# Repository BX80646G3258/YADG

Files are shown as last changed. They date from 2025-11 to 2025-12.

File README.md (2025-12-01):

# Yet Another Dogshit Gamepad
YADG is an open source gamepad built on the Arduino platform.
## Features
- 1000hz polling rate
- Polar joystick input
- Curve map
- Configurable deadzones
- Button remapping
- Button debounce settings
- idk what people care about lol
## Images
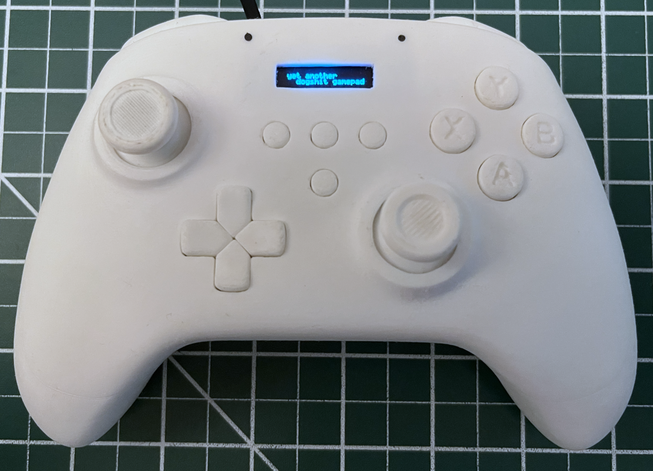
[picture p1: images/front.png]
front of YADG gamepad

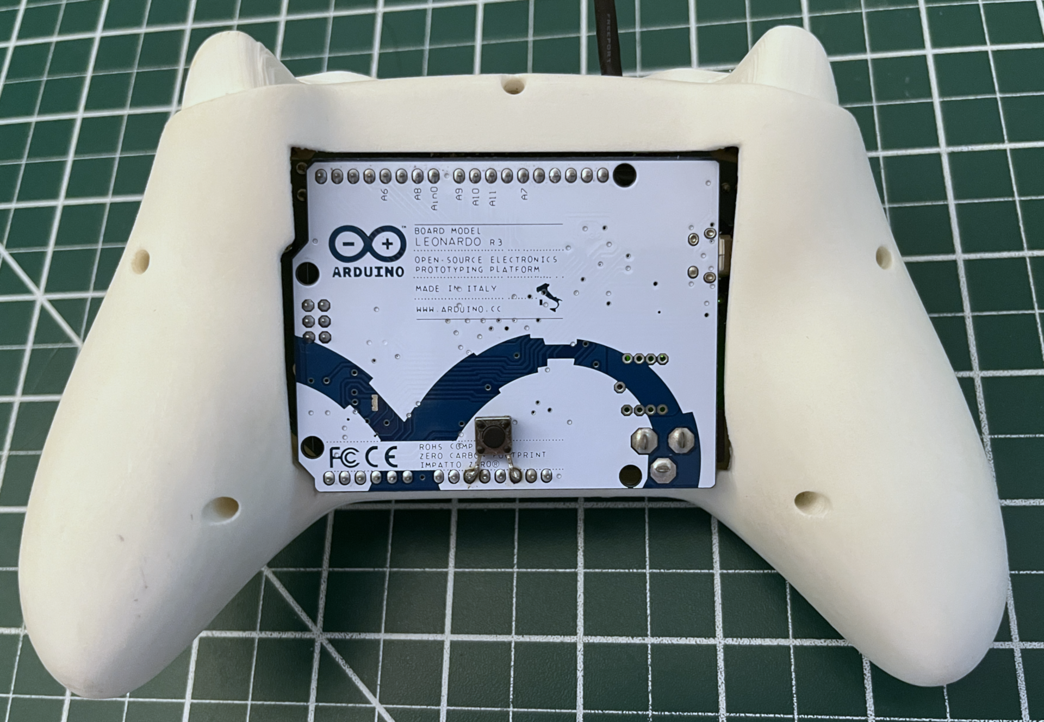
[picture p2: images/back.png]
back of YADG gamepad


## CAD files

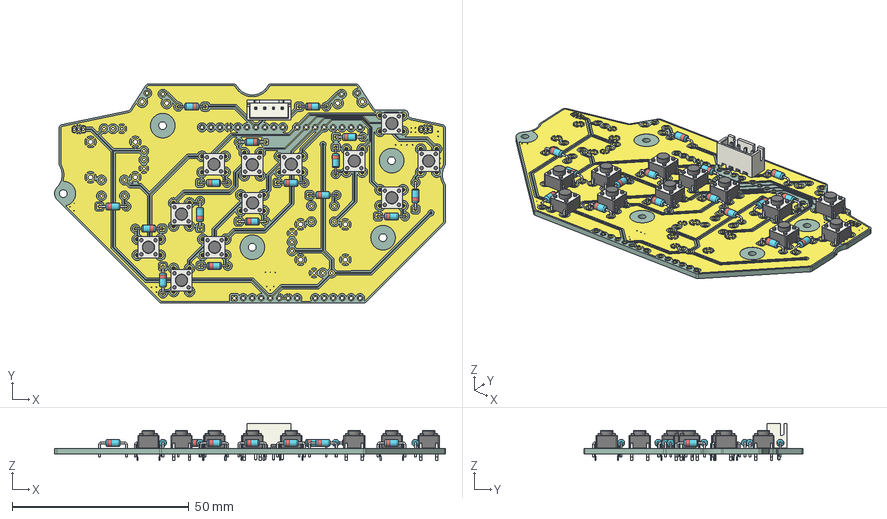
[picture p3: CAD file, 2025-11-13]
pcb/controller.step
110.5 x 61.9 x 10.5 mm
SW_PUSH_6mm_H5mm x 12
D_DO-35_SOD27_P7.62mm_Horizontal x 16
JST_XH_B4B-XH-A_1x04_P2.50mm_Vertical
controller_copper
controller_PCB

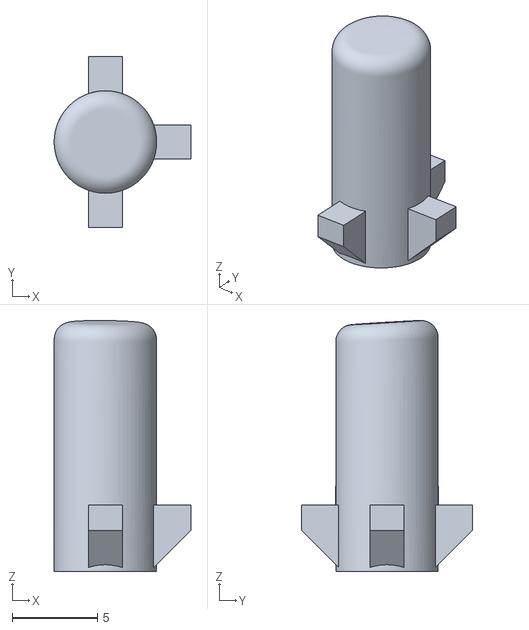
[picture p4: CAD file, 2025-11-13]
stl/start button.stl
8.00 x 10.0 x 14.7

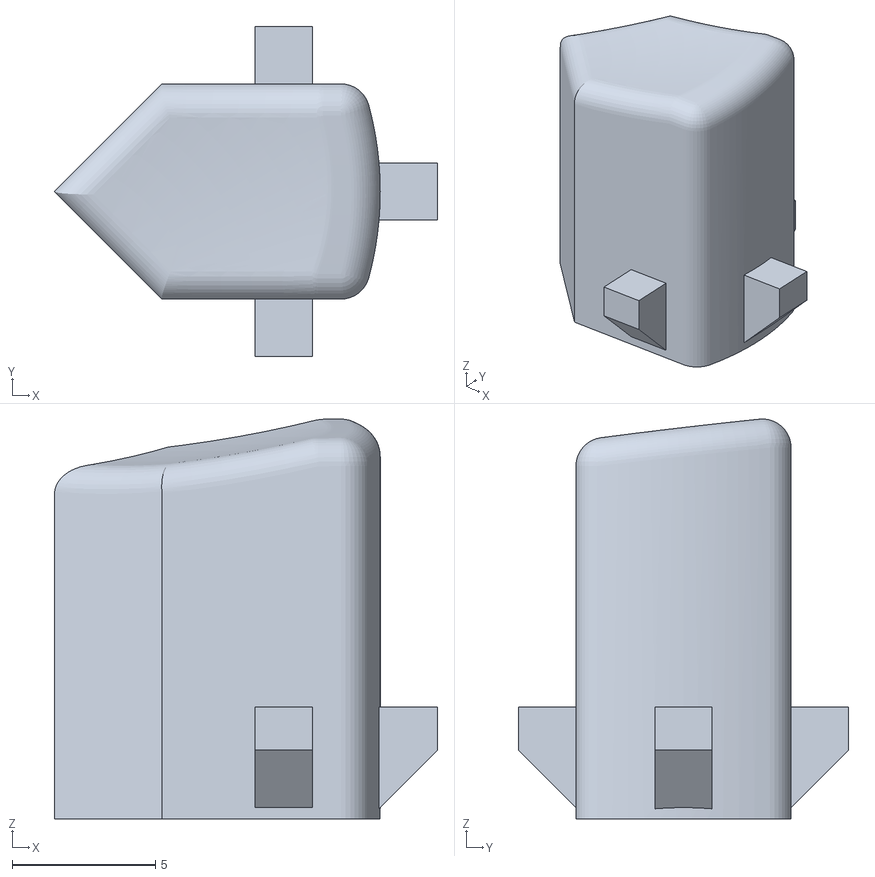
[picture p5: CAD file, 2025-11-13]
stl/dpad right button.stl
13.4 x 11.5 x 13.9

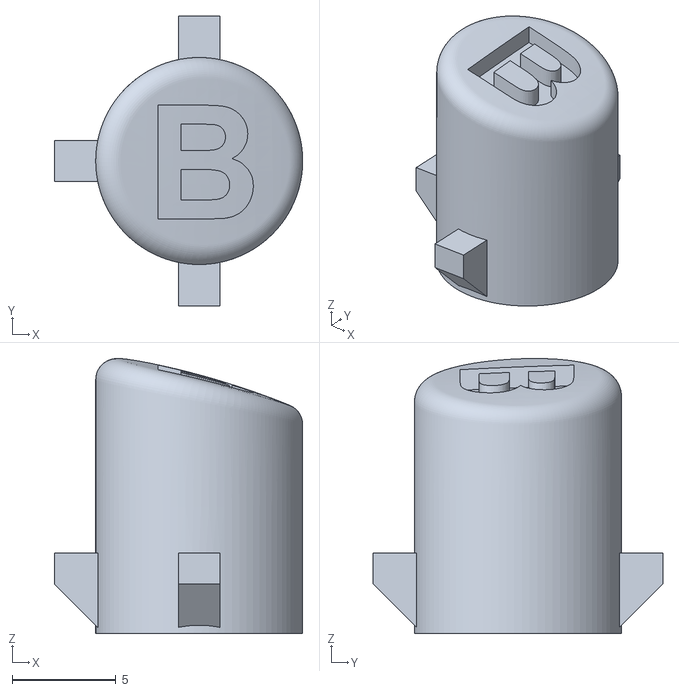
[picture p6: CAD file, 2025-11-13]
stl/button B.stl
12.0 x 14.0 x 13.3

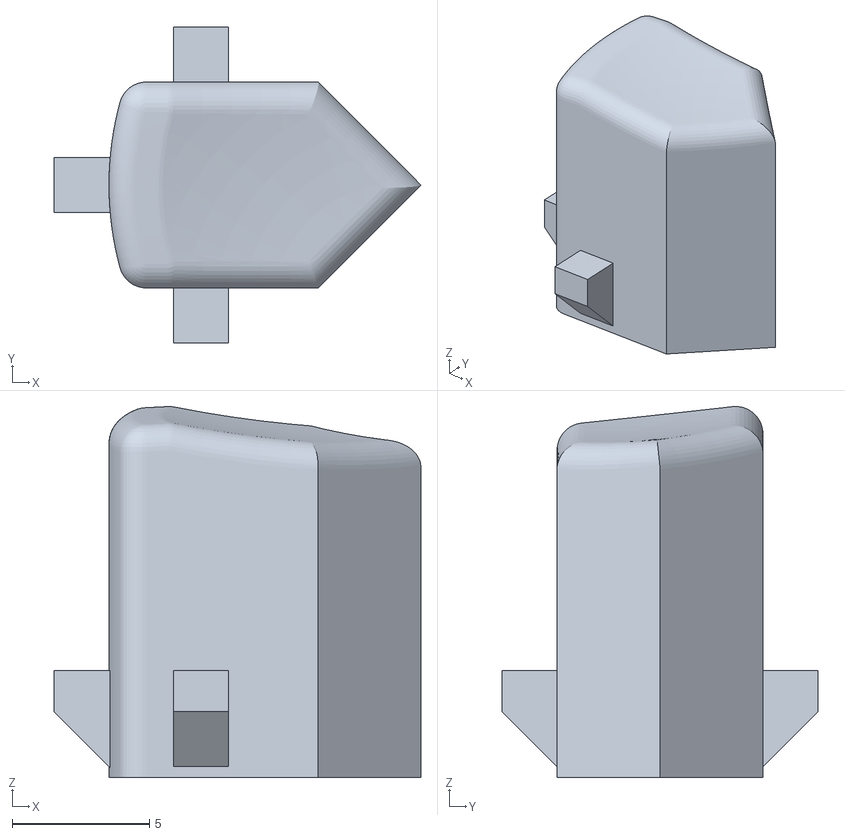
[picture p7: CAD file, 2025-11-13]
stl/dpad left button.stl
13.4 x 11.5 x 13.5

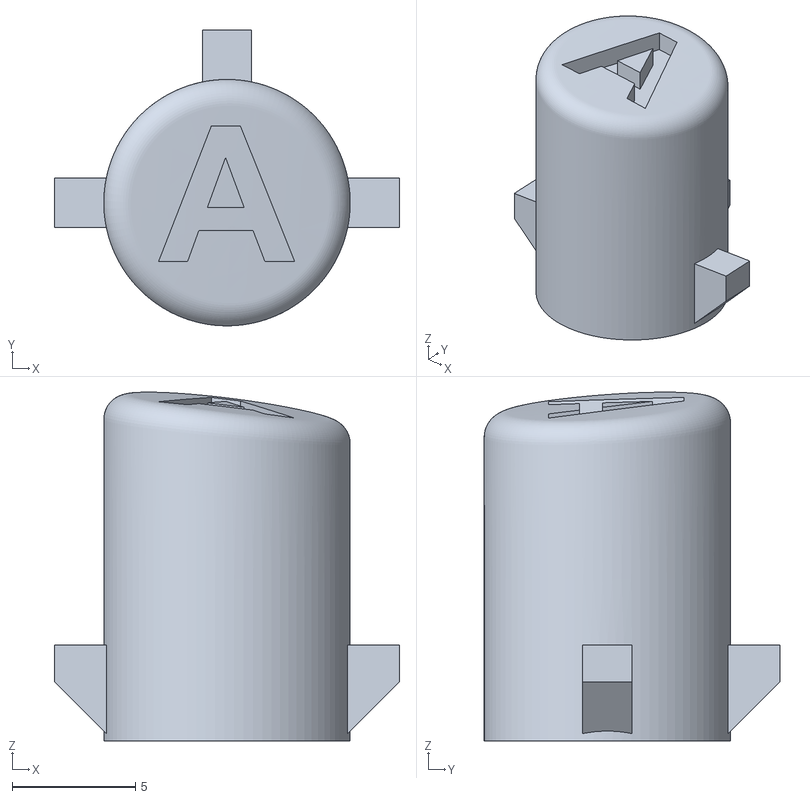
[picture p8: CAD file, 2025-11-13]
stl/button A.stl
14.0 x 12.0 x 14.2

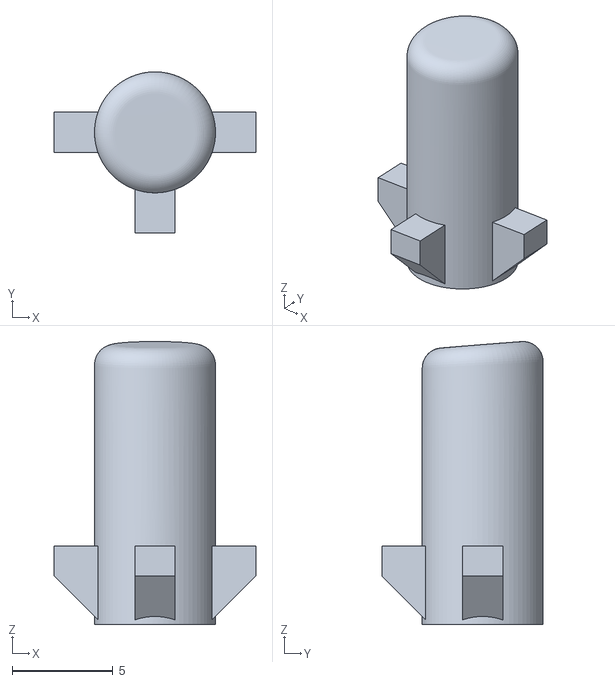
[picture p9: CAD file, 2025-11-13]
stl/config button.stl
10.0 x 8.00 x 14.0

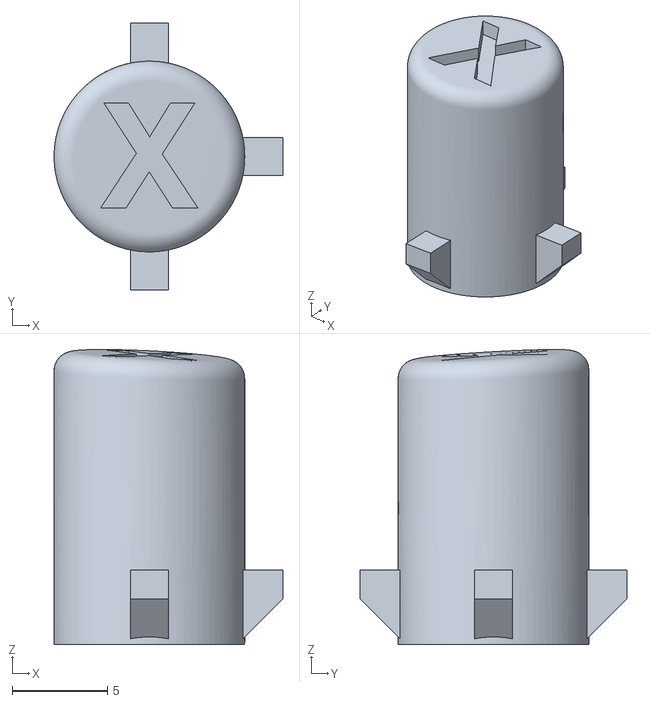
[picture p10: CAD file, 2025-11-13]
stl/button X.stl
12.0 x 14.0 x 15.5

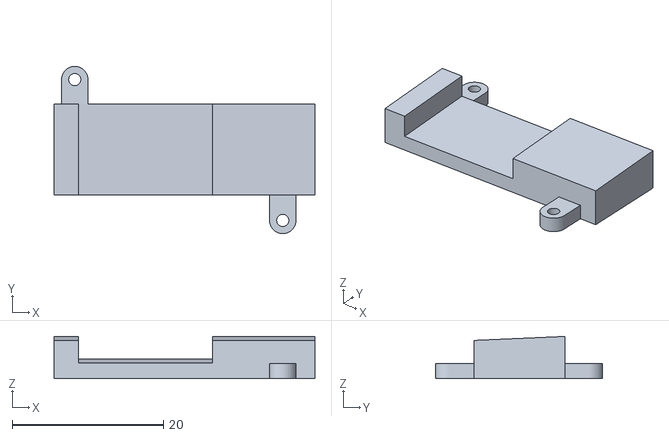
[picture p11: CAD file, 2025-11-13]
stl/display holder.stl
34.5 x 22.1 x 5.56

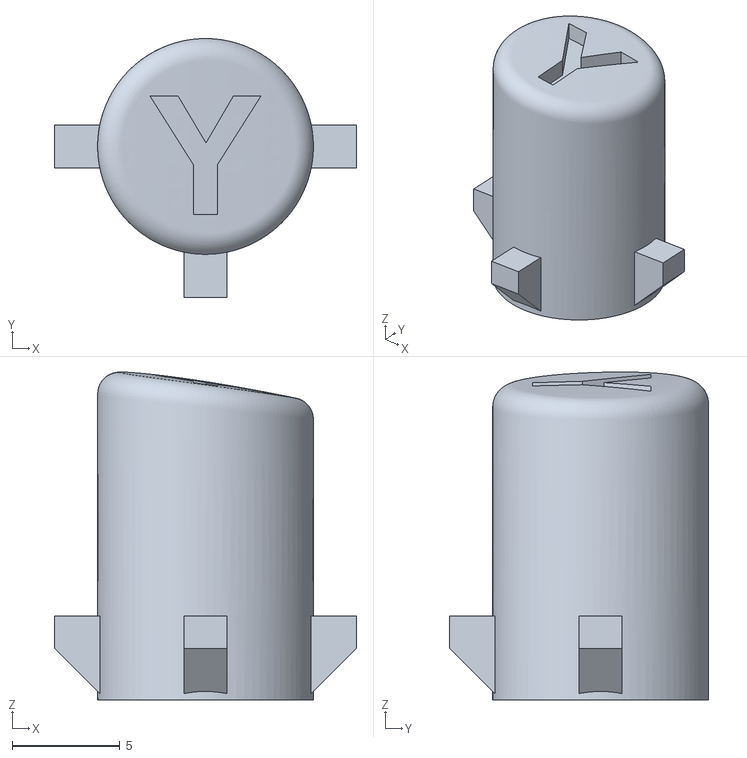
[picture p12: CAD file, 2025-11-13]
stl/button Y.stl
14.0 x 12.0 x 15.2

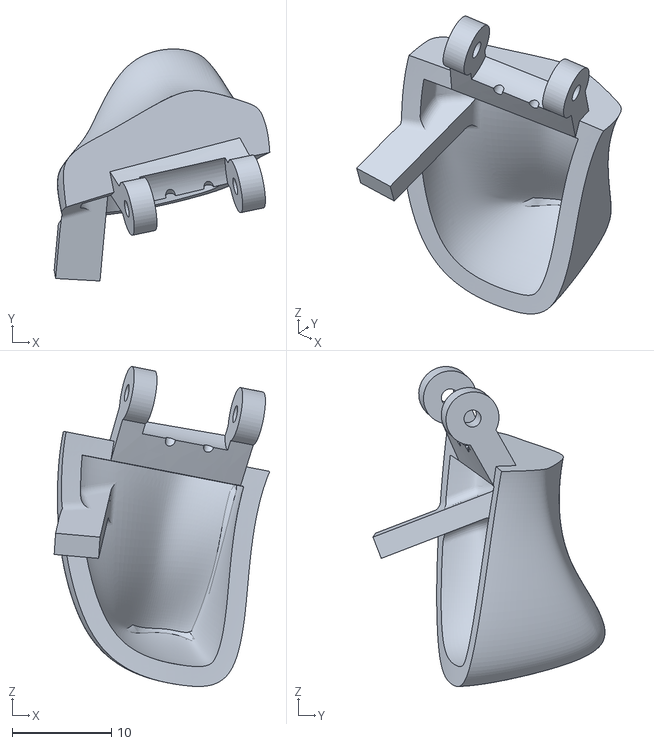
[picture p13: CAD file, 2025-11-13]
stl/trigger left.stl
21.7 x 23.4 x 32.2

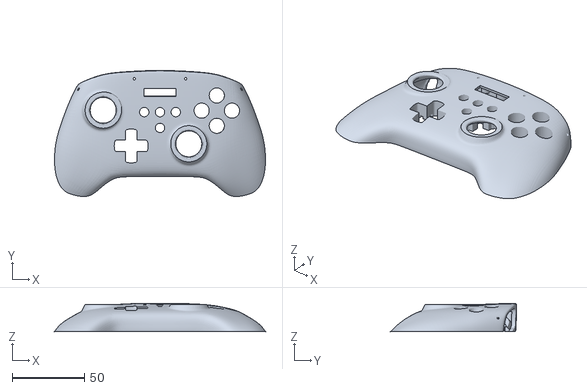
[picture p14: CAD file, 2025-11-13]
stl/shell top.stl
146.2 x 87.4 x 19.7

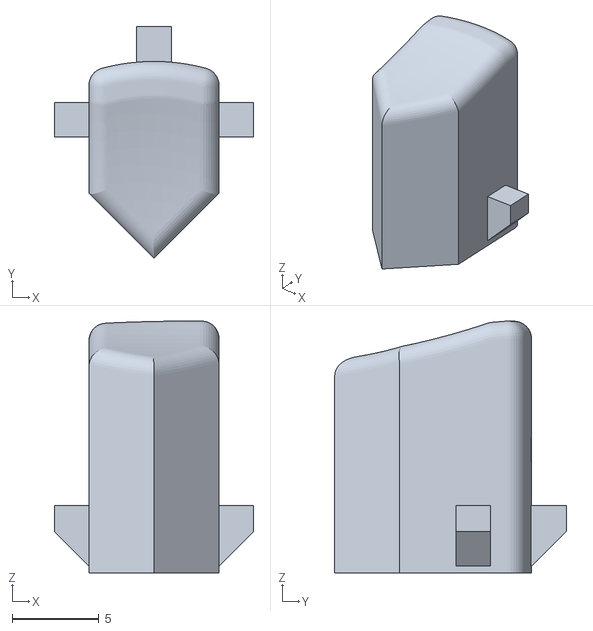
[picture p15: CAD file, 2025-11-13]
stl/dpad up button.stl
11.5 x 13.4 x 14.5

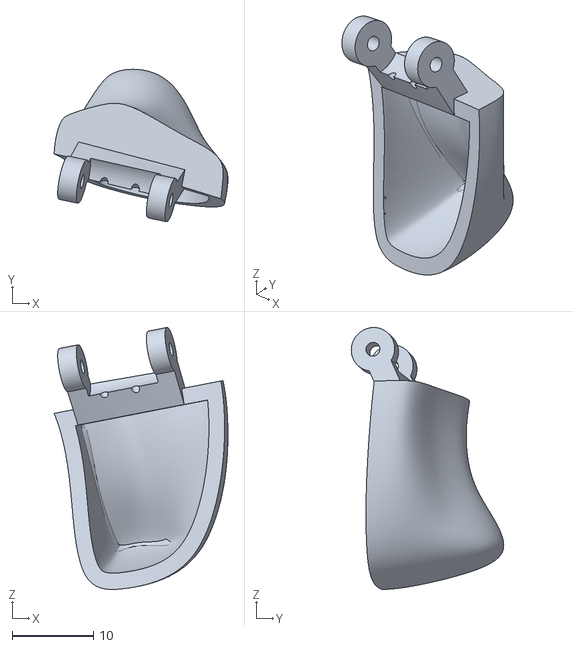
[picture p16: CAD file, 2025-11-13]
stl/trigger right.stl
21.4 x 18.8 x 32.2

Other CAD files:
stl/center button.stl
stl/back button.stl
stl/bumper right.stl
stl/dpad down button.stl
stl/bumper left.stl
stl/joystick.stl
stl/shell bottom.stl

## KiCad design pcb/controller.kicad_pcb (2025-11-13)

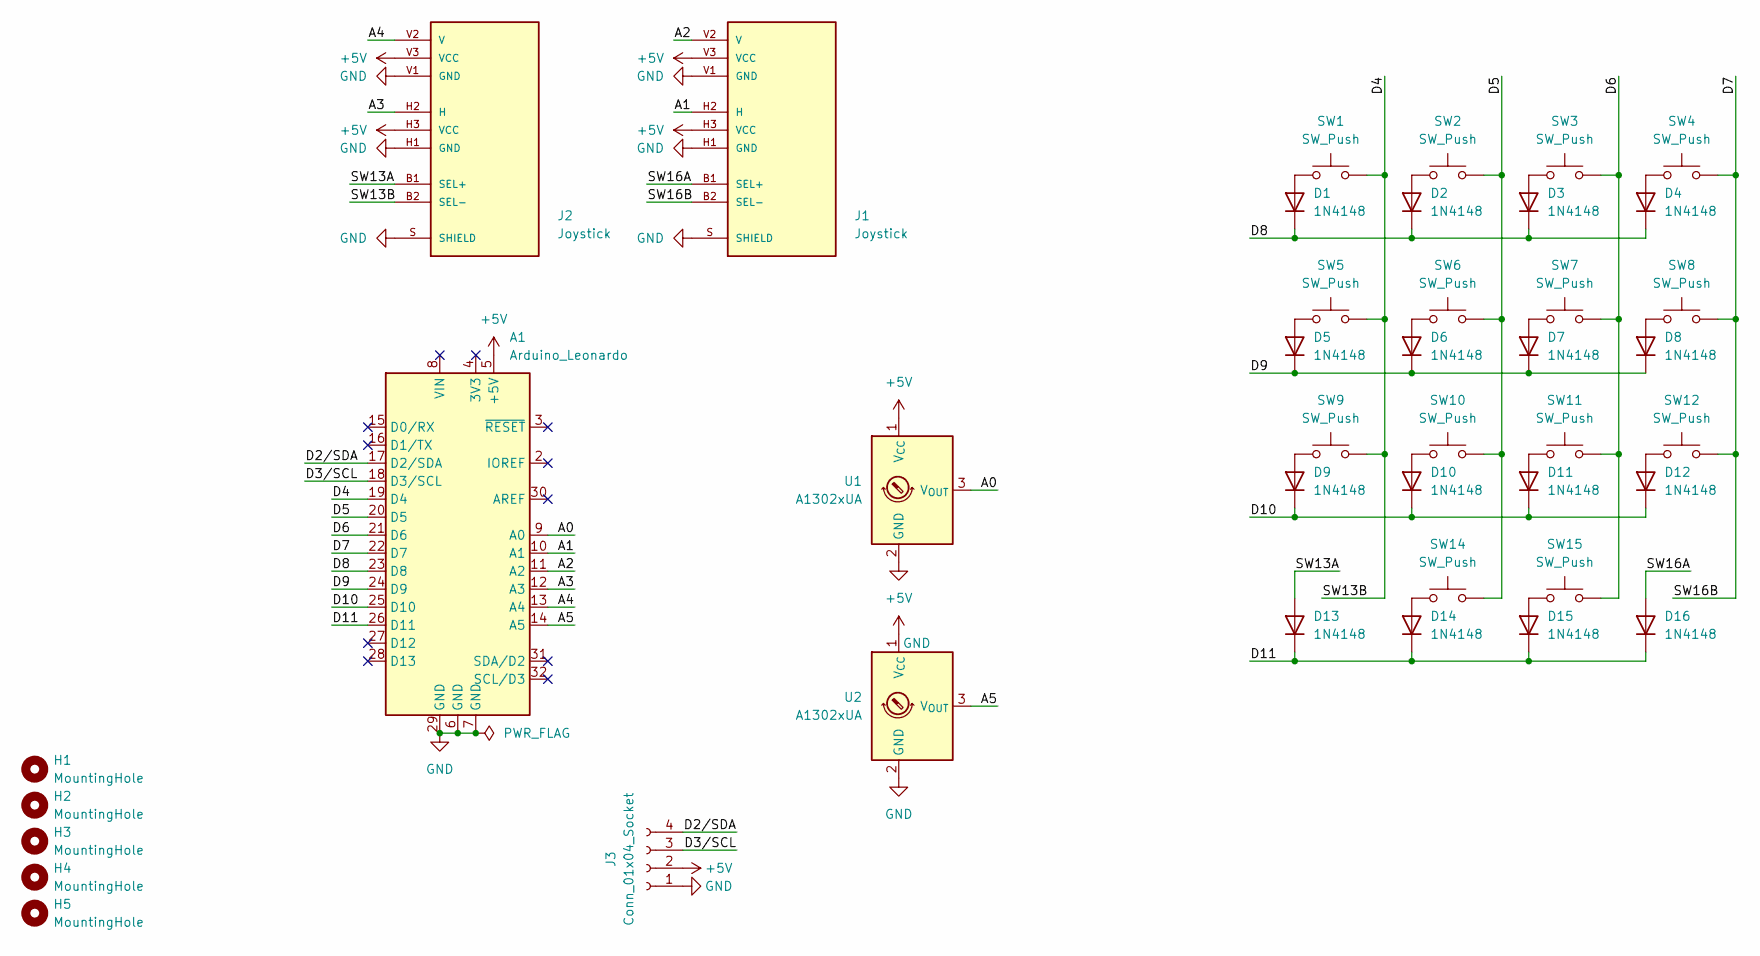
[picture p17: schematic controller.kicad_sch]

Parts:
A1: Arduino_Leonardo; Arduino_UNO_R3
D1, D2, D3, D4, D5, D6, D7, D8, D9, D10, D11, D12, D13, D14, D15, D16: 1N4148; D_DO-35_SOD27_P7.62mm_Horizontal
H1, H2, H3, H4, H5: MountingHole; MountingHole_2.2mm_M2_custom
J1, J2: Joystick
J3: Conn_01x04_Socket; JST_XH_B4B-XH-A_1x04_P2.50mm_Vertical
SW1, SW2, SW3, SW4, SW5, SW6, SW7, SW8, SW9, SW10, SW11, SW12: SW_Push; SW_PUSH_6mm_H5mm
SW14, SW15: SW_Push; SW_Tactile_SKHH_Angled
U1, U2: A1302xUA; TO-92S

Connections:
+5V: A1.5 (+5V), J1.H3 (VCC), J1.V3 (VCC), J2.H3 (VCC), J2.V3 (VCC), J3.2, U1.1 (V_{CC}), U2.1 (V_{CC})
/A0: A1.9 (A0), U1.3 (V_{OUT})
/A1: A1.10 (A1), J1.H2 (H)
/A2: A1.11 (A2), J1.V2 (V)
/A3: A1.12 (A3), J2.H2 (H)
/A4: A1.13 (A4), J2.V2 (V)
/A5: A1.14 (A5), U2.3 (V_{OUT})
/D2/SDA: A1.17 (D2/SDA), J3.4
/D3/SCL: A1.18 (D3/SCL), J3.3
/D4: A1.19 (D4), J2.B2 (SEL-), SW1.2, SW5.2, SW9.2
/D5: A1.20 (D5), SW2.2, SW6.2, SW10.2, SW14.2
/D6: A1.21 (D6), SW3.2, SW7.2, SW11.2, SW15.1
/D7: A1.22 (D7), J1.B2 (SEL-), SW4.2, SW8.2, SW12.2
/D8: A1.23 (D8), D1.1 (K), D2.1 (K), D3.1 (K), D4.1 (K)
/D9: A1.24 (D9), D5.1 (K), D6.1 (K), D7.1 (K), D8.1 (K)
/D10: A1.25 (D10), D9.1 (K), D10.1 (K), D11.1 (K), D12.1 (K)
/D11: A1.26 (D11), D13.1 (K), D14.1 (K), D15.1 (K), D16.1 (K)
/SW13A: D13.2 (A), J2.B1 (SEL+)
/SW16A: D16.2 (A), J1.B1 (SEL+)
GND: A1.6 (GND), A1.7 (GND), A1.29 (GND), J1.H1 (GND), J1.S (SHIELD), J1.V1 (GND), J2.H1 (GND), J2.S (SHIELD), J2.V1 (GND), J3.1, U1.2 (GND), U2.2 (GND)
unnamed: D1.2 (A), SW1.1
unnamed: D2.2 (A), SW2.1
unnamed: D3.2 (A), SW3.1
unnamed: D4.2 (A), SW4.1
unnamed: D5.2 (A), SW5.1
unnamed: D6.2 (A), SW6.1
unnamed: D7.2 (A), SW7.1
unnamed: D8.2 (A), SW8.1
unnamed: D9.2 (A), SW9.1
unnamed: D10.2 (A), SW10.1
unnamed: D11.2 (A), SW11.1
unnamed: D12.2 (A), SW12.1
unnamed: D14.2 (A), SW14.1
unnamed: D15.2 (A), SW15.2

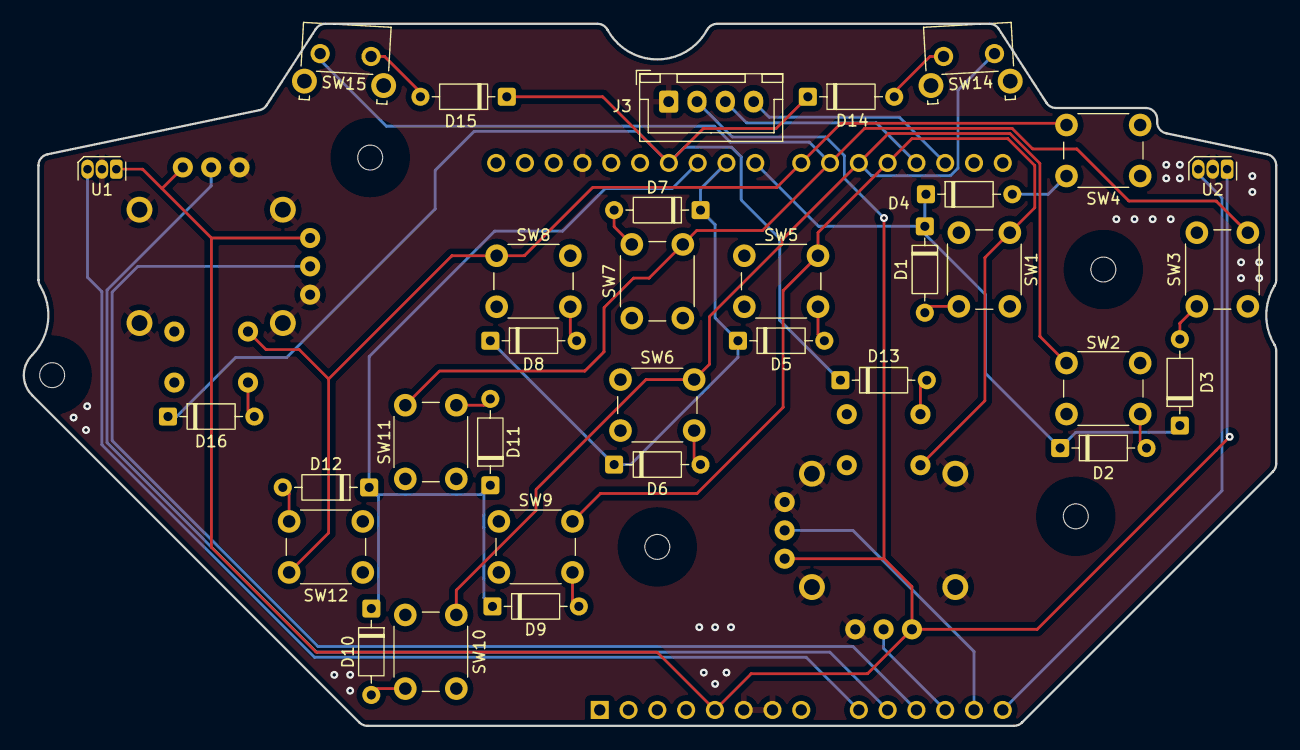
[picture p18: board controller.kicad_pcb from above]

Board: 2 copper layers, 110.5 x 61.9 mm, 41 parts (1 on the bottom side), 34 nets.

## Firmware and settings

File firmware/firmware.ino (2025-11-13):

#include "src/modified/USB_XInput_Descriptors.cpp"  // disgusting hack to modify USB_ConfigDescriptor

#include "Controller.h"
#include "ButtonMap.h"
#include "MenuSystem.h"
#include "UIStrings.h"
#include "Display.h"
#include "MemoryLogger.h"

#include <XInput.h>

using namespace ButtonMap;

const bool BENCHMARK = false;

uint32_t timestamp = micros();
uint16_t count = 0;

void showStartupLogo() {
  Display::cls();
  Display::print_P(UIStrings::STARTUP, 1, 2);
  Display::print_P(UIStrings::STARTUP2, 2, 4);
  delay(1000);
}

void setup() {
  Serial.begin(115200);
  // MemoryLogger::begin();

  controller.begin();
  MenuSystem::loadDefault();

  XInput.setAutoSend(false);
  XInput.begin();

  Display::begin();
  showStartupLogo();

  Display::cls();
}

void loop() {
  controller.update();

  if (controller.state.buttons[HW_CONF]) {
    XInput.releaseAll();
    XInput.send();
    MenuSystem::run();
    XInput.releaseAll();
    return;
  } else {
    // |= operation ensures that even when two hardware buttons are mapped to one software button, they both work
    bool buttons[sizeof(controller.state.buttons)] = { false };
    for (uint8_t i = 0; i < sizeof(buttons); i++) {
      buttons[controller.mapIndex(i)] |= controller.state.buttons[i];
    }

    for (uint8_t i = 0; i < sizeof(buttons) - 1; i++) {  // skip config button
      XInput.setButton(i, buttons[i]);
    }

    XInput.setJoystick(JOY_LEFT, controller.state.joystickLX, controller.state.joystickLY);
    XInput.setJoystick(JOY_RIGHT, controller.state.joystickRX, controller.state.joystickRY);
    XInput.setTrigger(TRIGGER_LEFT, controller.state.triggerL >> 8);
    XInput.setTrigger(TRIGGER_RIGHT, controller.state.triggerR >> 8);

    if (!BENCHMARK) {
      XInput.send();
    }
  }

  if (BENCHMARK) {
    count++;
    if (count > 1000) {
      // print the frequency of the main loop
      Serial.println((float)count * 1000000 / (micros() - timestamp));
      count = 0;
      timestamp = micros();
    }
  }
}

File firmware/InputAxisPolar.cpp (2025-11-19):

#include "InputAxisPolar.h"
#include "FastMath.h"
#include <Arduino.h>

using namespace FastMath;

InputAxisPolar::InputAxisPolar(uint8_t pinX, uint8_t pinY, bool invertX, bool invertY)
  : pinX(pinX), pinY(pinY), invertX(invertX), invertY(invertY), profiler(false) {

  pinMode(pinX, INPUT);
  pinMode(pinY, INPUT);

  resetAll();
}


void InputAxisPolar::calculateDomain(uint16_t& domainLow, uint16_t& domainHigh, uint8_t section) {
  domainLow = (uint32_t)deadzoneLow * history[section] >> 8;
  domainHigh = (uint32_t)deadzoneHigh * history[section] >> 8;
}

void InputAxisPolar::updateReciprocal(uint8_t section) {
  uint16_t domainLow, domainHigh;
  calculateDomain(domainLow, domainHigh, section);
  reciprocals[section] = ((uint32_t)1 << 16) / (domainHigh - domainLow);
}

void InputAxisPolar::update(int16_t& outX, int16_t& outY) {
  profiler.sample("read");
  uint16_t rawX = analogRead(pinX);
  uint16_t rawY = analogRead(pinY);

  profiler.sample("fltr");
  if (rawX > filteredX + hysteresis) {
    filteredX = rawX - hysteresis;
  } else if (rawX < filteredX - hysteresis) {
    filteredX = rawX + hysteresis;
  }

  if (rawY > filteredY + hysteresis) {
    filteredY = rawY - hysteresis;
  } else if (rawY < filteredY - hysteresis) {
    filteredY = rawY + hysteresis;
  }

  int16_t x = (int32_t)filteredX - centerX;
  int16_t y = (int32_t)filteredY - centerY;

  if (invertX) {
    x = -x;
  }
  if (invertY) {
    y = -y;
  }

  profiler.sample("atan");
  uint16_t theta = atan2Fast(y, x);

  profiler.sample("sqrt");
  // uint16_t r = sqrt32Approx((uint32_t)x * x + (uint32_t)y * y);  // 13 - 22 us
  uint16_t r = sqrt32((uint32_t)x * x + (uint32_t)y * y);  // 13 - 27 us
  // uint16_t r = sqrt((uint32_t)x * x + (uint32_t)y * y);  // 44 us

  profiler.sample("limt");
  uint8_t section = theta * RESOLUTION / 2048;
  theta = (theta - offset) & 2047;

  if (section >= RESOLUTION) {
    section = RESOLUTION - 1;
  }

  if (r > history[section]) {
    if (autoCalibrate) {
      history[section] = r;
      updateReciprocal(section);
    }
    r = UINT16_MAX;
  } else {
    uint16_t domainLow, domainHigh;
    calculateDomain(domainLow, domainHigh, section);
    if (r <= domainLow) {
      rotations = 0;
      lastTheta = 512;
      r = 0;
    } else if (r >= domainHigh) {
      r = UINT16_MAX;
    } else {
      r = (r - domainLow) * reciprocals[section];
    }
  }

  profiler.sample("writ");
  int16_t newX, newY;

  if (polarMode) {
    int16_t delta = theta - lastTheta;
    lastTheta = theta;
    if (delta > 1024) {
      rotations--;
    } else if (delta < -1024) {
      rotations++;
    }

    int16_t wrappedTheta = (int16_t)rotations * 2048 + (int16_t)theta - 512;

    if (wrappedTheta > (int16_t)maxTheta + 2048) {
      rotations--;
    } else if (-wrappedTheta > (int16_t)maxTheta + 2048) {
      rotations++;
    }

    wrappedTheta = -min(max(wrappedTheta, (int16_t)-maxTheta), (int16_t)maxTheta);
    r /= 2;
    newX = (int32_t)r * wrappedTheta / maxTheta;
    newY = r;
  } else {
    newX = (int32_t)r * sinFast(theta + 512) >> 16;
    newY = (int32_t)r * sinFast(theta) >> 16;
  }

  if (smoothingX == 0) {
    outX = newX;
  } else {
    outX = sLerpFast(newX, outX, 222 + smoothingX);
  }
  if (smoothingY == 0) {
    outY = newY;
  } else {
    outY = sLerpFast(newY, outY, 222 + smoothingY);
  }

  profiler.end();
}

void InputAxisPolar::resetCalibration() {
  for (uint8_t i = 0; i < RESOLUTION; i++) {
    history[i] = 0;
    reciprocals[i] = 0;
  }

  centerX = filteredX = analogRead(pinX);
  centerY = filteredY = analogRead(pinY);
}

void InputAxisPolar::resetAll() {
  deadzoneLow = .05 * UINT8_MAX;
  deadzoneHigh = .95 * UINT8_MAX;
  smoothingX = 0;
  smoothingY = 0;
  offset = 0;
  maxTheta = 135.0 * 2048 / 360;
  hysteresis = 2;
  autoCalibrate = true;
  polarMode = false;

  resetCalibration();
}

void InputAxisPolar::saveLoad(EEPROMBuffer& eeprom) {
  eeprom.readWrite(deadzoneLow);
  eeprom.readWrite(deadzoneHigh);
  eeprom.readWrite(smoothingX);
  eeprom.readWrite(smoothingY);
  eeprom.readWrite(offset);
  eeprom.readWrite(maxTheta);
  eeprom.readWrite(hysteresis);
  eeprom.readWrite(autoCalibrate);
  eeprom.readWrite(polarMode);
  eeprom.readWrite(centerX);
  eeprom.readWrite(centerY);
  for (uint8_t i = 0; i < RESOLUTION; i++) {
    eeprom.readWrite(history[i]);
    updateReciprocal(i);
  }
}
